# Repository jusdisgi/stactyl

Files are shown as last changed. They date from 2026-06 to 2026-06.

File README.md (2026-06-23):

# stactyl

A **portable, stowable split ergonomic keyboard** — *"stacks + dactyl"*: a true 3D scooped
keywell that **clamshells into a minimum-volume stowed stack** for travel.

stactyl reuses the **3D column geometry of the BastardKB TBK Mini** (a Dactyl Manuform Mini) but
is a clean, fresh design built around:

- **36 keys** — 3×5 finger matrix + 1 outboard pinky + 2 thumbs, **per hand** (18/hand).
- **Kailh PG1316S** ultra-low-profile switches (consigned at JLCPCB, `C9900170245`).
- **Regular XIAO nRF52840 BLE per half, matrix wiring + diodes** (the `tbkmini` recipe). Left half =
  split central. **Fully assembled (turnkey) at JLCPCB** — JLC places the XIAO from stock
  (`C17209540`), so no DNP and no hand-soldering. (Not the Plus — the matrix needs only 9 of the
  regular XIAO's 11 GPIO.)
- **No RGB** (keys only). Per-key + underglow RGB was designed then **shelved to a future variant**
  (2026-06-23) — routing LED power/data through the 2-layer flex necks is painful, and LEDs fight a
  travel board's battery/portability goal. See `CLAUDE.md` "Future variant — RGB (shelved)".
- A **thin rigid FR-4 "flex-by-thinness" plate**, built as a **BastardKB-style per-column comb**:
  each finger column is one full-width strip, columns joined by single serpentine necks, terminating
  at a rigid controller root (regular XIAO BLE) that folds into the keywell pocket. PCBA'd flat, then bent
  into the printed keywell. Standard rigid PCBA pipeline — no rigid-flex, no polyimide, no grid.
- A **printed 3D keywell** (from the **Cosmos** generator → STEP) that retains the switches and
  carries the formed plate.
- A **stow concept** that mates the two keywells past 180° to nest their convex hulls, held by
  matched magnet pads + a registration feature. Expect a chunky lens, not a pocketable clamshell.

## Toolchain note — two pipelines

Unlike every other board in `gittyup`, stactyl is **not** a pure-ergogen project, because ergogen
is 2D and cannot model a keywell.

- **Keywell / 3D shell:** generated in **Cosmos** (`ryanis.cool/cosmos`), exported as STEP,
  finished in CAD (Fusion/OnShape). See `cad/`.
- **Flat-plate PCB:** ergogen lays out the **per-column comb** (`config.yaml`) — staggered-column
  strips joined by serpentine necks, plus the rigid controller root. The Cosmos per-key transforms
  inform the column staggers; the necks absorb the curvature when bent, so no arc-length unfold is
  needed. Routed in KiCad. PCBA + KiKit panelization as usual.

## Layout

```
Per hand:  3 rows × 5 columns finger well   = 15
           + 1 outboard pinky (off home col) =  1
           + 2 thumb keys                     =  2
                                              ----
                                               18   ×2 hands = 36
```

## Repo contents

- `CLAUDE.md` — design brief / notes for future sessions (start here).
- `cad/` — Cosmos keywell config, the captured geometry parameter set (`keywell-params.md`),
  and exported STEP/STL.
- `config.yaml` — ergogen per-column comb layout (matrix points done; outline + PCB scaffolded — WIP).
- `footprints/` — local mirror of the footprints this board uses (canonical copies live in
  `../ergogen-footprints`).

## Status

Early build. Done: generator chosen (**Cosmos**), **keywell geometry locked** (18 keys/hand,
18×17 Choc spacing, tenting 18°, curve 5/15 — source of truth in `cad/stactyl-cosmos-expert.ts`),
and a **firmware skeleton** stood up (`../zmk-config-stactyl`).

**Reoriented 2026-06-22, amended 2026-06-23:** controller **nice!nano → regular XIAO nRF52840 BLE**,
fab **JLC DNP → JLC turnkey** (fully assembled — JLC places the XIAO), wiring **direct-pin → matrix +
diodes**. The brief Seeed + XIAO-Plus detour is reversed (matrix fits the regular XIAO's 11 GPIO; JLC
is cheaper + in stock), and **per-key/underglow RGB was shelved to a future variant** (LED routing
through the 2-layer flex necks is painful + LEDs fight portability). Stackup: **2-layer 0.6 mm ENIG**
(*not* 6-layer — it has to bend). Geometry and the flex-plate concept are unchanged.

STEP/STL export is **done**; the comb `config.yaml` points are stood up; the **firmware retarget is
done** (matrix on `xiao_ble//zmk`, builds green). Still to do, roughly in order: dial the comb column
staggers + finish the ergogen **outline** (column strips + serpentine necks + rigid root); the
regular-XIAO footprint; **the actual PCB — KiCad layout + matrix routing, both halves on one board,
schematic sync, then KiKit panelization**; MCU/LiPo/USB pockets + stow CAD; and a JLC BOM audit. See
the TODO list in `CLAUDE.md`.

## License

Original work © Hunter Cook. TBK Mini geometry is a **reference target only** (BastardKB,
CC BY-NC-SA 4.0) — stactyl is generated clean-room, not copied from their files.

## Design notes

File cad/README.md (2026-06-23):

# cad/ — stactyl keywell (Cosmos → STEP → CAD)

The 3D keywell does **not** come from ergogen (ergogen is 2D). It comes from the **Cosmos**
generator and is finished in CAD.

## Workflow

1. **Model in Cosmos** (`https://ryanis.cool/cosmos`) using `keywell-params.md` as the starting
   parameter set. Use **Advanced** for the sliders, then **Expert mode** (JS) to read out / lock
   the per-key transforms.
2. **Export STEP** (multi-part) — imports cleanly into Fusion / OnShape. Also export STL for quick
   test prints.
3. **Save artifacts here:** the Cosmos config (the JSON/URL state and/or the Expert-mode JS), the
   exported `.step`, and any `.stl`. Keep the config text-committed so the well is reproducible —
   don't rely on the exported mesh alone.
4. **Stow CAD** (later): bring both halves into one assembly in the *stowed pose*, nest the convex
   hulls (rotate past 180°), and cut **matched magnet pads + a registration feature** as negatives
   of each other. See `../CLAUDE.md` "Stow / mate concept".

## Files (to be added)

- `stactyl-cosmos-expert.ts` — **present.** Expert-mode config: the per-key transforms, and the
  reproducible source of the geometry (paste into Cosmos Expert mode to reload). This is the bridge
  to the flat plate.
- `keywell-params.md` — **present.** Human-readable rationale + locked-parameter record.
- `stactylleft.step` / `stactylright.step` — **present** (exported from Cosmos 2026-06-19). The
  keywell solids for the stow CAD + case.
- `stactyl-case*/stactyl-plate*.stl` — **present** (quick-print meshes: case halves + plate top/bottom).

## Why Cosmos (vs Dactyl-Manuform / Dometyl)

Clean **STEP** export for the stow CAD + magnet-pad booleans; **Expert-mode per-key transforms**
to inform the per-column comb staggers for the flat plate; native low-profile switch support; actively maintained web
tool, no OpenSCAD/opam toolchain to stand up. Decided 2026-06-18.

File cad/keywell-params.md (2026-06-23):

# stactyl keywell — parameter set

Generator: **Cosmos** (`https://ryanis.cool/cosmos`). These were a **starting point** to dial in
against the physical TBK Mini, *not* a precise clone of it — Hunter likes the TBK feel but exact
matching is **not** a hard requirement (confirmed 2026-06-18), so PG1316S ergonomics win where they
conflict.

> **STATUS — geometry LOCKED 2026-06-18.** The model has been built and renders cleanly in Cosmos.
> The authoritative geometry now lives in **`stactyl-cosmos-expert.ts`** (Expert-mode per-key
> transforms); this file is the human-readable rationale. Final values that differ from the
> starting targets below: **finger spacing 18×17 mm** (standard Choc, not 17×17), **tenting 18°**,
> outboard pinky **1u** (custom rounded/tri caps later in CAD), and **microcontroller/connectors
> disabled** in Cosmos (controller + LiPo go in custom under-keywell pockets per the brief).
> **STEP/STL export DONE 2026-06-19** (`stactylleft/right.step` + case/plate STLs in this dir). Still
> to do: translating the transforms into the ergogen flat plate.

## Geometry target — Dactyl Manuform Mini lineage

The TBK Mini is a BastardKB **Dactyl Manuform Mini**. Its repo ships baked STLs/KiCad, **not a
parametric config**, so "match TBK Mini" = start from the well-known Dactyl-Manuform(-Mini)
defaults and tune. Classic DM defaults (tshort / carbonfet lineage), expressed in the terms
Cosmos uses:

| Concept (DM term) | DM default | In Cosmos | stactyl start |
|---|---|---|---|
| Column curvature (`alpha`) | π/12 = **15°**  | Column curvature (per-row angle) | **15°** |
| Row curvature (`beta`) | π/36 = **5°** | Row curvature (per-column angle) | **5°** |
| Tenting (`tenting-angle`) | ~π/12 = 15° | Tenting | **18°** * |
| Center column (`centercol`) | 3 (ring) | Column the well pivots around | **ring (3)**  |
| Center row (`centerrow`) | nrows − 3 | — | middle row |

\* TBK Mini ships with optional **30°** detachable tents on top of its built-in tilt; 18° in the
well + hand/desk tilt is a sane low-profile starting tent. Dial 15–25°.

### Per-column Z / stagger (the part that makes it feel like a Dactyl)

Cosmos exposes per-column **stagger** and **height** offsets. Seed with the canonical DM column
profile (relative to the home/ring column), then tune to taste:

| Column | Finger  | Rel. stagger (Y, mm) | Rel. height (Z, mm) |
|---|---|---|---|
| 0 (outer) | pinky | -12 *(see note)* | +2 *(slightly high)*|
| 1 | pinky | 0 | 0 |
| 2 | ring | +5 | -1 |
| 3 (center) | middle  | +6  *(longest)* | -2  *(deepest)* |
| 4 | index | +3 | -1 |

> stactyl drops the TBK's **outer 6th column** and keeps the inner 5. Column 0 above is the
> *kept* outer pinky column. The **+1 outboard pinky** key is a separate extra key anchored off
> the pinky home column (xiphos / TOTEM style), not a 6th finger column — place it in Cosmos as a
> single added key, angled outward, **not** by adding a column.

## Switch & spacing — PG1316S

| Param | Value | Source / note |
|---|---|---|
| Switch model in Cosmos | **Choc V1** | Closest low-profile Z-height/socket proxy; Cosmos has no PG1316S |
| Keycap | Choc / stock | Stock PG1316S caps are ~16×16; Cosmos Choc cap is close |
| X spacing (columns) | **17 mm** | Hunter's `presets.pg1316s`: `ks: 17` (mikefive-style 17×17) |
| Y spacing (rows) | **17 mm** | `kp: 17` |
| Switch body | 13 × 16 mm | Kailh PG1316S datasheet |

**Important:** in stactyl the switches are retained by the **printed keywell plate**, not the
PCB. So Cosmos's switch choice only matters for the **scoop Z-height and socket pockets** — the
real PG1316S pockets get modeled as a custom step on the plate. Use Cosmos for the scoop surface,
the per-key planes, and the shell; don't rely on its socket for retention.

## What we actually need *out* of Cosmos

1. **STEP of the keywell solid** → stow CAD (nest hulls, add magnet pads + registration) and the
   printed case. Cosmos STEP imports cleanly into Fusion/OnShape.
2. **Per-key transforms** (position + orientation of every key plane) from **Expert mode** → inform
   the ergogen **per-column comb** staggers (the flat plate is a BastardKB-style comb, not a developed
   grid; the serpentine necks absorb the curvature when bent, so no exact arc-length unfold). This is
   the bridge between the 3D well and the 2D plate.

## Thumb cluster (2 keys) — TODO

DM Mini ships 3 thumbs; stactyl drops to 2. Cosmos has a dedicated thumb-cluster editor — start
from its 2-key "tucked" preset, angle ~ -15° to -25°, positioned under the index/middle home
keys. Exact position/angle still open.

## Open geometry items

- [x] Build the Cosmos model + capture Expert per-key transforms (`stactyl-cosmos-expert.ts`).
      2026-06-18. STEP/STL exported 2026-06-19 (see below).
- [x] Finalize 2-key thumb position/angle and the outboard pinky key. 2026-06-18 (pinky 1u).
- [x] Spacing decided: **18×17** (standard Choc), revisit only if a printed test well says otherwise.
- [x] **Export STEP + STL** from Cosmos into this folder. 2026-06-19 — `stactylleft/right.step` +
      case/plate STLs. Geometry of record for the case + stow CAD; no longer depends on the live URL.
- [ ] Validate scoop depth is shallow enough for each column strip to flex onto its keys + the
      inter-column necks to reach, within FR-4 bend tolerance (the flex-by-thinness premise depends
      on a shallow well).
- [ ] **MCU / LiPo / USB pockets (custom CAD).** Cosmos's auto holder + connector are disabled, so
      on the exported STEP model: a **regular XIAO nRF52840 BLE** pocket (smaller than a nice!nano — easier
      on the tight shell + stow volume), a LiPo pocket, and a USB-C cutout aligned to the **XIAO's**
      onboard port (no separate connector). Decoupled from the generator on purpose.
      *(Controller: nice!nano → regular XIAO nRF52840 BLE, finalized 2026-06-23; see `../CLAUDE.md`.)*

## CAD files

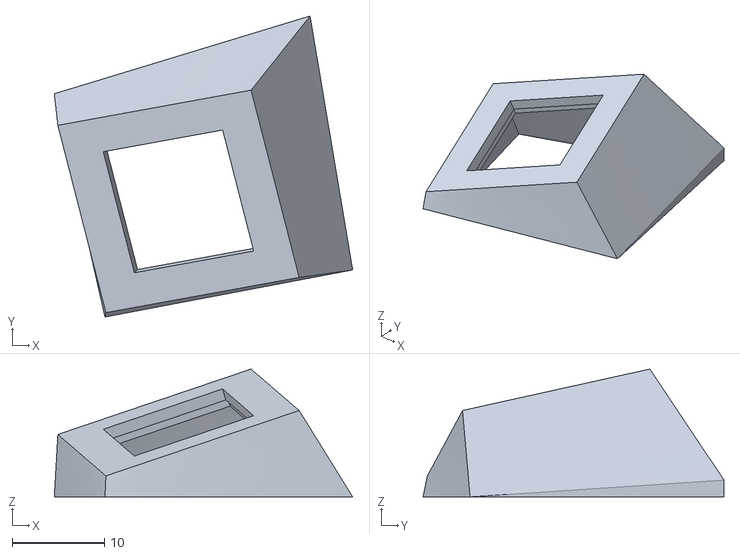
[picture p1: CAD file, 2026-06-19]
cad/stactyl-casetest.stl
32.3 x 32.6 x 13.8

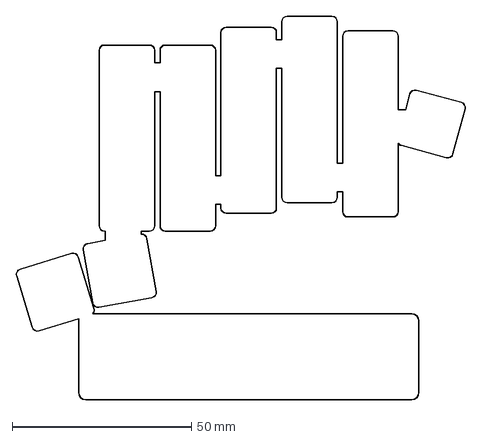
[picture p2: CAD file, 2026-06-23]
output/outlines/board.dxf
125.5 x 107.0 mm

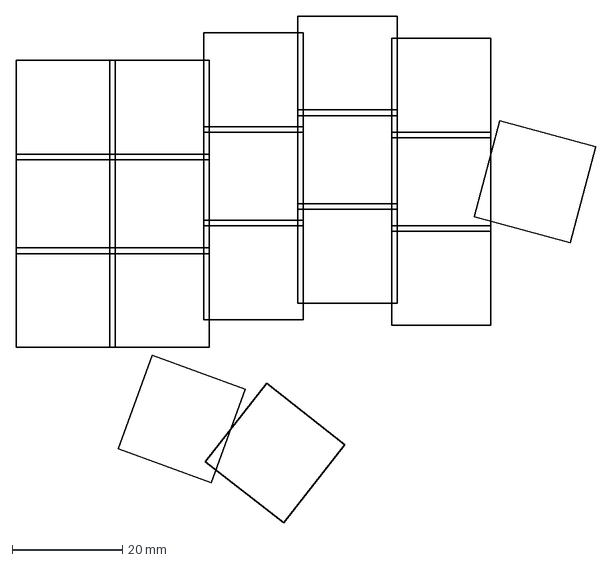
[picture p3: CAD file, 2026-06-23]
output/points/demo.dxf
105.0 x 91.8 mm

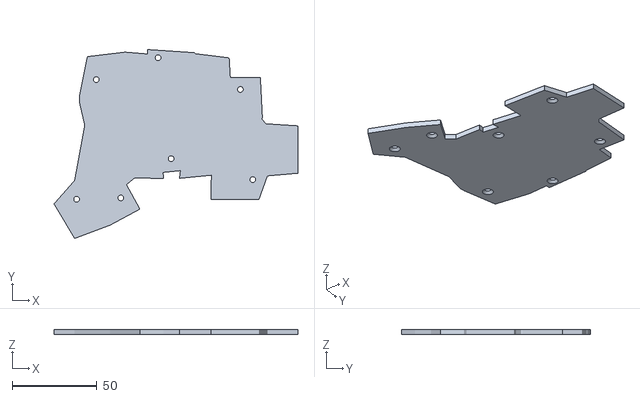
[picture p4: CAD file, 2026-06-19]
cad/stactyl-platebottomright.stl
144.2 x 111.6 x 3.00

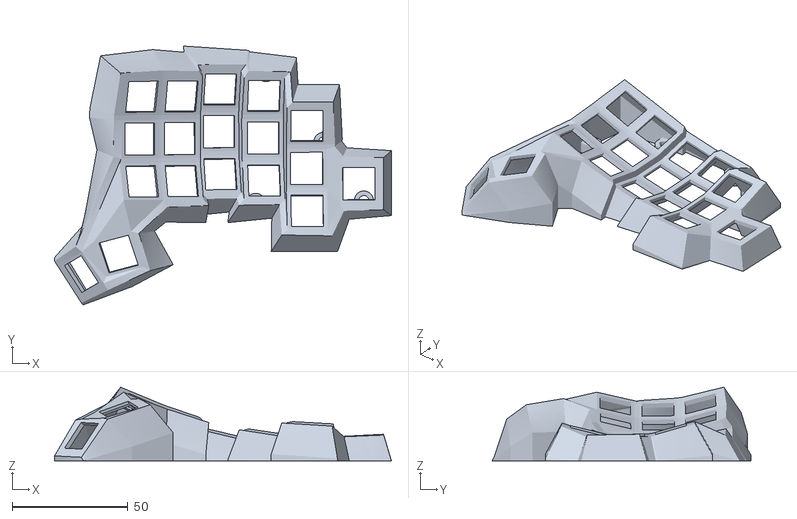
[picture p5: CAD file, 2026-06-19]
cad/stactyl-caseright.stl
145.3 x 111.6 x 31.8

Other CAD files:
cad/stactyl-platebottomleft.stl
cad/stactyl-caseleft.stl

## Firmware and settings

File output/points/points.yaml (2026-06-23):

finger_inner_bottom:
    x: 0
    'y': -2
    r: 0
    meta:
        stagger: -2
        spread: 17
        splay: 0
        origin:
            - 0
            - 0
        orient: 0
        shift:
            - 0
            - 0
        rotate: 0
        adjust: {}
        width: 18
        height: 18
        padding: 17
        autobind: 10
        skip: false
        asym: both
        colrow: inner_bottom
        name: finger_inner_bottom
        column_net: C4
        row_net: R2
        zone:
            key:
                padding: kp
                spread: ks
            columns:
                inner:
                    key:
                        column_net: C4
                        stagger: stagger_finger_inner
                        splay: splay_finger_inner
                    rows: {}
                    name: inner
                index:
                    key:
                        column_net: C3
                        stagger: stagger_finger_index
                        splay: splay_finger_index
                    rows: {}
                    name: index
                middle:
                    key:
                        column_net: C2
                        stagger: stagger_finger_middle
                        splay: splay_finger_middle
                    rows: {}
                    name: middle
                ring:
                    key:
                        column_net: C1
                        stagger: stagger_finger_ring
                        splay: splay_finger_ring
                    rows: {}
                    name: ring
                pinky:
                    key:
                        column_net: C0
                        stagger: stagger_finger_pinky
                        splay: splay_finger_pinky
                    rows: {}
                    name: pinky
            rows:
                bottom:
                    row_net: R2
                home:
                    row_net: R1
                top:
                    row_net: R0
            name: finger
        col:
            key:
                column_net: C4
                stagger: stagger_finger_inner
                splay: splay_finger_inner
            rows: {}
            name: inner
        row: bottom
        bind:
            - 10
            - 10
            - 0
            - 0
finger_inner_home:
    x: 0
    'y': 15
    r: 0
    meta:
        stagger: -2
        spread: 17
        splay: 0
        origin:
            - 0
            - 0
        orient: 0
        shift:
            - 0
            - 0
        rotate: 0
        adjust: {}
        width: 18
        height: 18
        padding: 17
        autobind: 10
        skip: false
        asym: both
        colrow: inner_home
        name: finger_inner_home
        column_net: C4
        row_net: R1
        zone:
            key:
                padding: kp
                spread: ks
            columns:
                inner:
                    key:
                        column_net: C4
                        stagger: stagger_finger_inner
                        splay: splay_finger_inner
                    rows: {}
                    name: inner
                index:
                    key:
                        column_net: C3
                        stagger: stagger_finger_index
                        splay: splay_finger_index
                    rows: {}
                    name: index
                middle:
                    key:
                        column_net: C2
                        stagger: stagger_finger_middle
                        splay: splay_finger_middle
                    rows: {}
                    name: middle
                ring:
                    key:
                        column_net: C1
                        stagger: stagger_finger_ring
                        splay: splay_finger_ring
                    rows: {}
                    name: ring
                pinky:
                    key:
                        column_net: C0
                        stagger: stagger_finger_pinky
                        splay: splay_finger_pinky
                    rows: {}
                    name: pinky
            rows:
                bottom:
                    row_net: R2
                home:
                    row_net: R1
                top:
                    row_net: R0
            name: finger
        col:
            key:
                column_net: C4
                stagger: stagger_finger_inner
                splay: splay_finger_inner
            rows: {}
            name: inner
        row: home
        bind:
            - 10
            - 10
            - 10
            - 0
finger_inner_top:
    x: 0
    'y': 32
    r: 0
    meta:
        stagger: -2
        spread: 17
        splay: 0
        origin:
            - 0
            - 0
        orient: 0
        shift:
            - 0
            - 0
        rotate: 0
        adjust: {}
        width: 18
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

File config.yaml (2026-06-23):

meta:
  engine: 4.1.0
  name: stactyl
  version: 0.2
  ref: &kb_ref "stactyl v0.2"
  author: huntercook
  url: &kb_url https://github.com/jusdisgi/stactyl
  footprint: &switch_footprint "switch_pg1316s"

# =============================================================================
# stactyl flat plate — PER-COLUMN COMB (BastardKB-style). Model confirmed with
# Hunter 2026-06-22; see ../stactyl/CLAUDE.md "PCB approach".
# -----------------------------------------------------------------------------
# NOT a grid of facets. Each finger column is ONE continuous full-width strip
# (keys at row pitch; the strip flexes along the scoop in the gaps BETWEEN
# switches — no neck-down between rows). Adjacent columns are joined by a single
# serpentine neck (alternating top/bottom). Everything terminates at a rigid
# controller root (regular XIAO nRF52840 BLE + power/reset/battery) that folds into the
# under-keywell pocket. Outboard pinky necks off the pinky strip; the 2-key
# thumb cluster is its own strip on a serpentine tail off the root.
#
# Wiring: ~5x4 matrix (cols C0..C4, rows R0..R3) + one SOD-323 diode/key. KEYS
# ONLY — RGB shelved to a future variant (2026-06-23). Column lines run UP each
# strip (never cross a neck); only the ~4 row lines cross the necks (easy on 2
# layers now that there's no LED power/data).
#
# WHAT'S RUNNABLE HERE: the points (matrix layout: 5 finger columns + outboard
# pinky + 2 thumbs). The staggers/splays are a STARTING POINT — dial them in
# ergogen against cad/stactyl-cosmos-expert.ts + a bent test print (the necks
# absorb the residual, so this does NOT need an exact arc-length unfold).
# The OUTLINE (strip rects + necks + root) and the PCB section (footprints) are
# scaffolded in comments at the bottom — iterate those in ergogen on Hunter's
# machine (per workspace memory, generators run there, not sandbox).
# =============================================================================

units:
  # PG1316S preset — mirrored from ../xiphos / ../LightFury.
  kx: 16
  ky: 16
  ks: 17    # column spacing (PG1316S, 17 across a row)
  kp: 17    # row spacing (key-to-key down a column strip)
  kcow: 16  # cutout width  (= stock cap; caps bottom out by design)
  kcoh: 16  # cutout height
  keycw: 16
  keych: 16

  # Trace / via (from ../LightFury)
  signal_trace_width: 0.2
  pwr_trace_width: 0.25
  gnd_trace_width: 0.25
  via_size: 0.5    # JLCPCB no-extra-charge min 0.56 (KiCad default 0.8)
  via_drill: 0.3   # JLCPCB no-extra-charge min 0.3

  # Finger column stagger — flat-plate Y offset per column. STARTING values;
  # tune so the bent comb lands on its keywell posts (necks take up the rest).
  stagger_finger_pinky: -4
  stagger_finger_ring: 3
  stagger_finger_middle: 5
  stagger_finger_index: 0
  stagger_finger_inner: -2

  # Finger column splay (deg). Keep ~0 for flat strips — the keywell's row
  # curvature is absorbed by the inter-column necks, not in-plane splay.
  splay_finger_pinky: 0
  splay_finger_ring: 0
  splay_finger_middle: 0
  splay_finger_index: 0
  splay_finger_inner: 0

  # --- comb OUTLINE knobs (tune these, re-run ergogen, view output/outlines/) ---
  strip_w: 15.5   # key-PAD width (min ~14.7 = PG1316S land).
  pad_h: 14       # key-pad height (< kp=17 so the board pinches between keys = relief).
  spine_w: 5      # narrow backbone width between keys (the in-column flex zone).
  strip_h: 52     # spine height: covers all 3 rows (2*17 + one key).
  neck_l: 15      # inter-column neck length — spans the WIDE spine-to-spine gap (~12mm).
  neck_w: 10      # inter-column neck height (tall enough to bridge a column stagger step).
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

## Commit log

2026-06-19 Create dactyl form with http://ryanis.cool/cosmos/beta
    [stactyl-caseleft.stl, stactyl-caseright.stl, stactyl-casetest.stl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]
2026-06-23 Early work on BOM
    [demo.dxf]
2026-06-23 Create points and outline draft.
    [board.dxf]
